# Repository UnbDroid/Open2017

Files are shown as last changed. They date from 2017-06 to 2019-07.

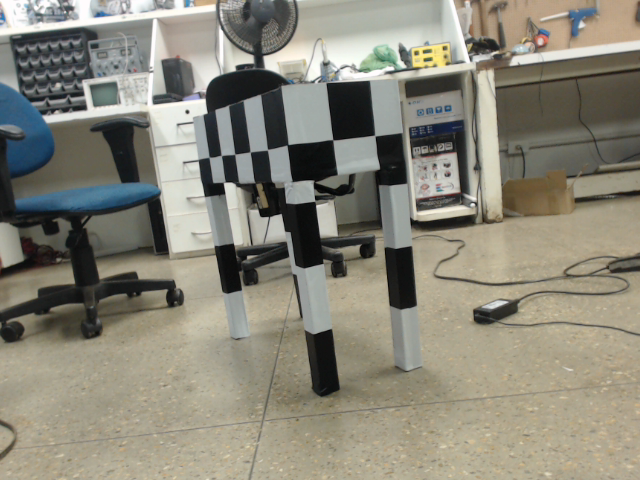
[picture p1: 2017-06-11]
Codigos/Vision/src/053.png

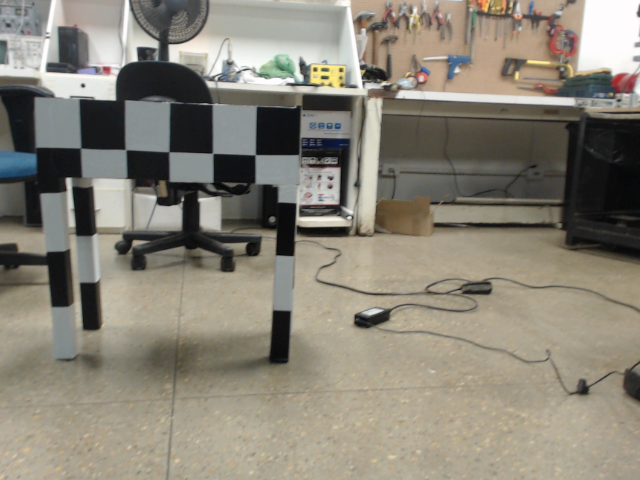
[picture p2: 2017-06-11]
Codigos/Vision/src/025.png

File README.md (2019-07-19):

# Open2017
Development repository for DROID's project files for Latin American Robotics Competition (LARC) 2017 category IEEE-Open  
The robot is supposed to milk a a cow (simulation of a real world problem)
# Photo of the robot:


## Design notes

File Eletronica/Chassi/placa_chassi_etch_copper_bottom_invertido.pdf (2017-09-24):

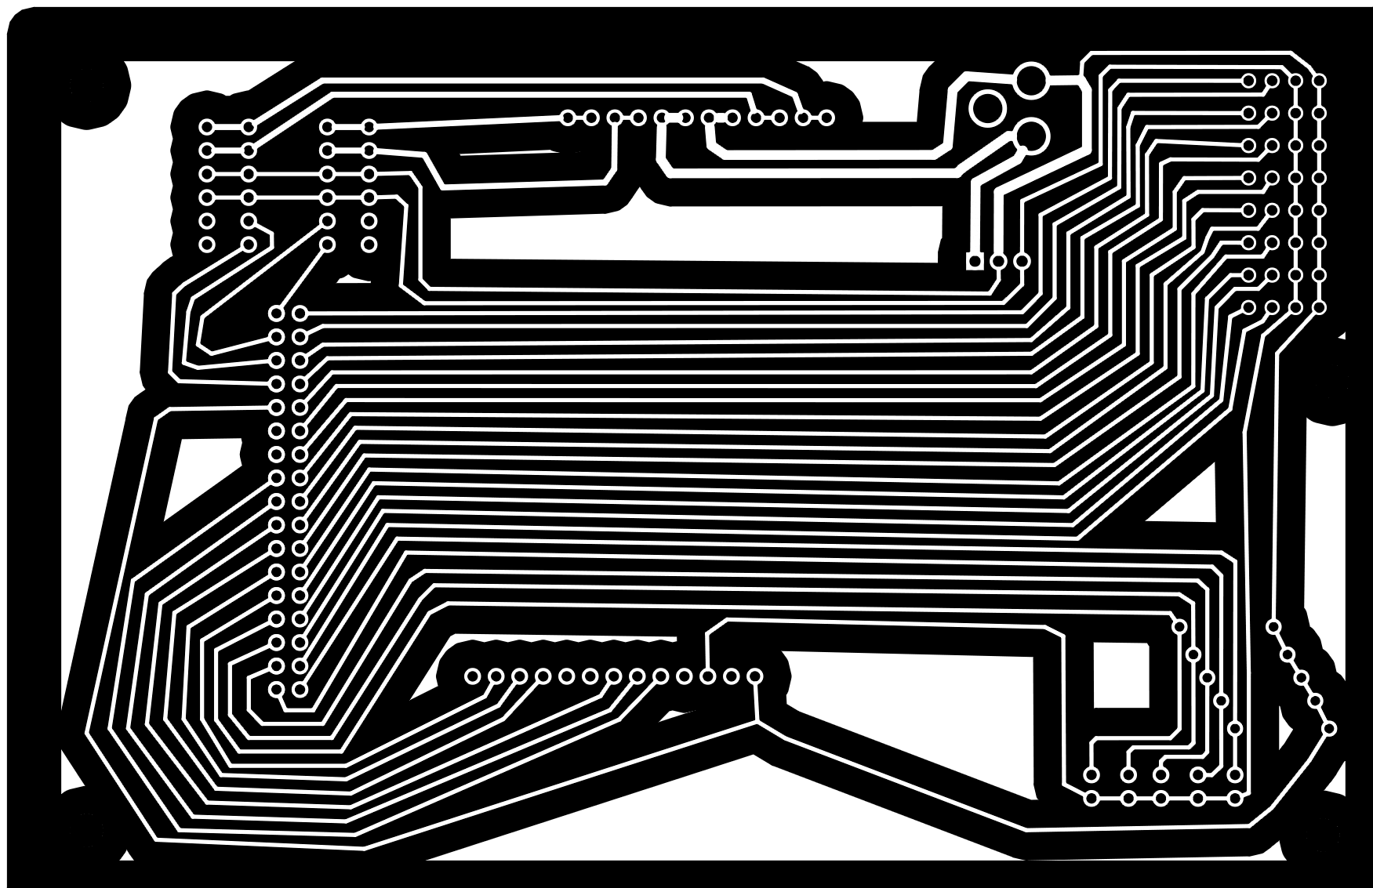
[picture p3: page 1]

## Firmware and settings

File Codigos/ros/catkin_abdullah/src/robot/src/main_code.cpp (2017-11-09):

	#include <cmath>
	#include <vector>
	#include <iostream>
	#include <fstream>
	using namespace std;

	#define PI 3.14159265f


/*---------------------------------------definicoes ROS-------------------------------------------*/
	#include "ros/ros.h"
	#include "ros/time.h"
	#include "arduino_msgs/StampedInt32.h"
	#include "arduino_msgs/StampedInt64.h"
	#include "arduino_msgs/StampedFloat32.h"
	#include "arduino_msgs/StampedFloat64.h"	

	ros::Publisher pubM_int64;
	ros::Publisher pubM_float64;
	ros::Publisher pubN_int32;
	ros::Publisher pubN_float32;

	ros::Publisher pubDEBUG;

	ros::Publisher pub_VCestrategia;
	ros::Subscriber sub_VCestrategia;

	ros::Subscriber subM_int64;
	ros::Subscriber subM_float64;
	ros::Subscriber subN_int32;
	ros::Subscriber subN_float32;

	ros::Publisher pubVis_int32;
	ros::Subscriber subVis_float64;
/*------------------------------------------------------------------------------------------------*/

/*-----------------------------------declaracoes das funcoes--------------------------------------*/
	bool ehSonar(int id);
	bool ehToque(int id);
	void messageMInt64Cb( const arduino_msgs::StampedInt64& aM_int64_msg);
	void messageMFloat64Cb( const arduino_msgs::StampedFloat64& aM_float64_msg);
	void messageNInt32Cb( const arduino_msgs::StampedInt32& aN_int32_msg);
	void messageNFloat32Cb( const arduino_msgs::StampedFloat32& aN_float32_msg);
	void messageVisFloat64Cb( const arduino_msgs::StampedFloat64& vis_float64_msg);
	void VCestrategiaCB(const arduino_msgs::StampedInt32& VCestrategia_msg);
	void initROS();
	void SendFloatMega(int id, double data);
	void SendIntMega(int id, long long int data);	
	void SendFloatUno(int id, float data);
	void SendIntUno(int id, long int data);
	void SendVel(float DIR, float ESQ);
	void GiraEmGraus(float angulo);
	float DeGrausParaRadianos(float angulo);
	float DeRadianosParaDegraus(float angulo);
	vector<float> AnaliseLugarDaVaca(float x1, float y1, float x2, float y2, float theta);
	void TrajetoriaSuaveAteAVaca(float x1, float y1, float x2, float y2, float theta);
	void andaRetoDistVelTempo(float dist, float vel);
	void algoritmo();
	void atualizaLocalizacao(int id, float value);
	void inicializarVariaveis();
	vector<int> posicaoPraMatriz(int x, int y);
	vector<float> matrizPraPosicao(int i, int j);
	void preencheMatriz();
	double rotacoesPorSegundoParaLinear(float dado);
	bool ehGarra(int id);
	void SendIntVCestrategia(int id, long int data);
	void andaRetoDistVelIntegrando(float distancia, float vel);
	void buscaMelhorCaminho(int NoAtual, int iO, int jO);
	class NoDoMapa;
	class Vertice;
	int deIJparaCasaNoVetor(int i, int j);
	vector<int> deCasaNoVetorParaIJ(int casaNoVetor);
	void printaGrafo();
	bool criaGrafoComPesos();
	void buscaMelhorCaminho(int NoAtual, int iO, int jO);
	bool EhNoEixoX(int no1, int no2);
	int AnguloQuePrecisaPraGirar(int noObjetivo);
	bool ehPraPassarNaPorta();
	void rotinaPassarNaPorta();
	void andaDevagarChecandoPortaAteAcabarOVao(bool praFrente,int sensorParaChecar, bool comecandoNaParede);
	int checaAnguloComTolerancia();
	int absolutoINT(int valor);
	float absolutoFLOAT(float valor);
	void AndaDeNoAtualParaObjetivo();
/*------------------------------------------------------------------------------------------------*/

/*-----------------------------------definicoes mapeamento----------------------------------------*/
	#define CASA_INICIAL_I 4
	#define CASA_INICIAL_J 0


	
	#define CASA_I_BALDE  
	#define CASA_J_BALDE 

	#define CASA_I_VACA1 
	#define CASA_J_VACA1 

	#define CASA_I_VACA2 
	#define CASA_J_VACA2

	#define CASA_I_VACA3 
	#define CASA_J_VACA3

	int noAtual = 24;
 

	//////////////define na hora que a posicao eh escolhida 
	
	#define CASA_I_MESA_PEGAR 4
	#define CASA_J_MESA_PEGAR 5

	#define CASA_I_MESA_DEVOLVER 5
	#define CASA_J_MESA_DEVOLVER 1
	
	#define LADO_Y_I_DA_ARENA 400
	#define LADO_X_J_DA_ARENA 300

	vector<float> ladosQuadrado(2);	
	
	#define I 0
	#define J 1

	#define COLUNAS_MAPA 6
	#define LINHAS_MAPA 8

	//vector<vector<int> > mapa(LINHAS_MAPA, vector<int>(COLUNAS_MAPA));
	class Vertice{
		public:	
			double peso;
	        NoDoMapa* noAdjacente;
	};

	class NoDoMapa{
		public:
			vector<float> centro;
	        int NumeroDoNo;
	        int informacaoDoQuadrado;
	        bool Visitado;
			vector<Vertice> adjacentes;
			void adicionaAdjacente(int casaNo, int peso);
		NoDoMapa(){
			centro = vector<float>(2);
		}
	};


	vector<vector<NoDoMapa> > GrafoMapa(LINHAS_MAPA, vector<NoDoMapa>(COLUNAS_MAPA));
/*------------------------------------------------------------------------------------------------*/

/*-------------------------------------definicoes locomocao---------------------------------------*/

	#define VELOCIDADE_MAXIMA 1.3f
	#define VELOCIDADE_ALTA	1.0f
	#define VELOCIDADE_NORMAL 0.75f
	#define VELOCIDADE_BAIXA 0.5f
	#define VELOCIDADE_BAIXISSIMA 0.2f
	
	#define USDIREITA 1
	#define USESQUERDA 0

	#define GIRA 300
	#define VEL_REF_DIR 301
	#define VEL_REF_ESQ 302
	#define TRAVAR 303
	#define VELOCIDADE_CRU 304

	#define PARAMETRO_DERRAPAGEM_ROTACOES_METROS 8.625f ///era pra ser 8	
	#define DIAMETRO_MEDIO 9.5125f


	#define EIXO_XPOSITIVO 0
	#define EIXO_XNEGATIVO 1 
	#define EIXO_YPOSITIVO 2
	#define EIXO_YNEGATIVO 3

	#define TOLERANCIA_ANGULO 15
	#define PERDIDO_BRODER -1

	#define AJUSTE_POS_ACHAR_PORTA 5.0

	vector<float> posicao(3);

	double velocidadeIntegrada;
	vector<int> SequenciaDeNosParaSeguir;

	#define X 0
	#define Y 1
	#define ANGULO 2
	
	#define ANGULO_MINIMO_CORRECAO_GIRO 45
	#define CORRECAO_GIRO 6

	#define ACABOU_GIRO 1
	#define ACABOU_ATUAL 2
	#define DISTANCIA_MIN_AJUSTE_VACA 30.0f
	
	#define PASSO_LOCOMOCAO 50
	#define PASSINHO 4

	#define ANDAR 1
	#define GIRAR 2
/*------------------------------------------------------------------------------------------------*/

/*---------------------------------definicoes dos sensores US-------------------------------------*/



	#define FRENTE_R 0
	#define FRENTE_L 3

	#define TRAS_R 2
	#define TRAS_L 5

	#define LADO_R 4
	#define LADO_L 7

	#define CIMA_R 1
	#define CIMA_L 6

	#define VALOR_VAO 25

	#define US_MAX_DIST 200

	#define NUM_IDEN_US 100

	#define QUANTIDADE_SENSOR_US 8
	
	#define TAMANHO_MEDIANA 5
	#define VALOR_MEDIANA 2
	//sinal chega do arduino com o id(USn) = (n-1) + NUM_IDEN_US... exemplo: id do US5 = (5-1) + 100 = 104

	#define alfa_US 0.8f

	class Us{
  		public:
	  		float valor;
	  		vector<float> valores;
	  		long long int vezes_lido;
		Us(){
			valores = vector<float>(TAMANHO_MEDIANA);
		}
	};

	vector<Us> ultrassom(QUANTIDADE_SENSOR_US);
/*------------------------------------------------------------------------------------------------*/

/*-----------------------------definicoes dos sensores de TOQUE-----------------------------------*/
	#define TOQUE1 0
	#define TOQUE2 1
	#define TOQUE3 2
	#define TOQUE4 3
	#define TOQUE5 4
	#define TOQUE6 5
	#define TOQUE7 6

	#define TOQUE8 7
	#define TOQUE9 8

	#define NUM_IDEN_TOQUE 200
	#define QUANTIDADE_SENSOR_TOQUE 9

	vector<bool> toque(QUANTIDADE_SENSOR_TOQUE);//(QUANTIDADE_SENSOR_TOQUE, false);
/*------------------------------------------------------------------------------------------------*/

/*-------------------------------------------Garra------------------------------------------------*/
	#define QUANTIDADE_MOTORES_GARRA 1

	#define MOTOR_PASSO_X 0 //MOVE MOTOR NO EIXO X PARA SE ALINHAR
	#define ANDA_ROBO 1  //MANDA ROBO IR PARA FRENTE PARA PEGAR COPO
	#define ACABOU_GARRA 2 //INFORMA QUE ACABOU MOVIMENTAÇÃO

	#define ANGULO_TANQUE 3 //ANGULO DO ROBO AO TANQUE
	#define DISTANCIA_TANQUE 4 //DISTANCIA DO ROBO AO TANQUE

	#define DISTANCIA_AVANCO_ROBO 20

	#define TANQUE 10
	#define GARRA 20

	#define NUM_IDEN_VISAO 600

/*
	#define QUANTIDADE_MOTORES_GARRA 5
	
	#define MOTOR_PASSO_X 0 
	#define MOTOR_PASSO_Y 1
	#define MOTOR_SERVO_COTOVELO 2
	#define MOTOR_SERVO_PULSO 3 
	#define MOTOR_SERVO_ATUADOR 4

	#define ACABOU_GARRA 666
	
	#define ANDA_PRA_FRENTE_GARRA 667 
	
	#define NUM_IDEN_GARRA 600

	#define VELOCIDADE_COPO 0.24f

	#define PEGA_COPO 10
	#define DESCARREGA_COPO 20 
	#define DEVOLVE_COPO 30
*/
/*------------------------------------------------------------------------------------------------*/

/*--------------------------------------definicoes da VISAO---------------------------------------*/
	#define NUM_IDEN_VISION 500
	#define VIS_X1 1
	#define VIS_Z1 2
	#define VIS_X2 3
	#define VIS_Z2 4
	#define VIS_ERR 5
	#define VIS_NOTFOUND 6
	double cow_pos_x1, cow_pos_x2, cow_pos_z1, cow_pos_z2, cow_pos_err;
	bool foundCow = 0;
/*------------------------------------------------------------------------------------------------*/

class Ocupacao{
	public:
		bool giro;
		bool garraGeral;
};

Ocupacao ocupado;


template<typename ItemType>
unsigned Partition(ItemType* array, unsigned f, unsigned l, ItemType pivot)
{
    unsigned i = f-1, j = l+1;
    while(true)
    {
        while(pivot < array[--j]);
        while(array[++i] < pivot);
        if(i<j)
        {
            ItemType tmp = array[i];
            array[i] = array[j];
            array[j] = tmp;
        }
        else
            return j;
    }
}

template<typename ItemType>
void QuickSortImpl(ItemType* array, unsigned f, unsigned l)
{
    while(f < l)
    {
        unsigned m = Partition(array, f, l, array[f]);
        QuickSortImpl(array, f, m);
        f = m+1;
    }
}

template<typename ItemType>
void QuickSort(ItemType* array, unsigned size)
{
    QuickSortImpl(array, 0, size-1);
}

bool ehSonar(int id)
{
	id = id - NUM_IDEN_US;
	if (id < QUANTIDADE_SENSOR_US && id >= 0)	 return true;
	else	return false;
}

bool ehToque(int id)
{
	id = id - NUM_IDEN_TOQUE;
	if (id < QUANTIDADE_SENSOR_TOQUE && id >= 0)	 return true;
	else	return false;
}



void Delay(double time)
{
    double t1=0, t0=0;
    t0 = ros::Time::now().toSec();
    while((t1-t0)<time && ros::ok()){
        t1 = ros::Time::now().toSec();
        ros::spinOnce();
    }
}
/*----------------------------------------callbacks------------------------------------------------*/
	void messageMInt64Cb( const arduino_msgs::StampedInt64& aM_int64_msg)
	{
		if(ehSonar(aM_int64_msg.id))
		{
			int usPos = aM_int64_msg.id - NUM_IDEN_US; 
			int valor ;
			valor = (aM_int64_msg.data <= 0.1) ? US_MAX_DIST : aM_int64_msg.data;	
			//sonar[aN_int32_msg.id - NUM_IDEN_US] = valor * alfa_US + sonar[aN_int32_msg.id - NUM_IDEN_US] * (1 - alfa_US);
			float valorf = (float)valor ; 
			long long int iterator = ultrassom[usPos].vezes_lido ;
		    ultrassom[usPos].valores[iterator % TAMANHO_MEDIANA] = valorf;
		    float valores[TAMANHO_MEDIANA];
		    for(unsigned i = 0; i < TAMANHO_MEDIANA; ++i)
		      	valores[i] = ultrassom[usPos].valores[i];
		    QuickSort(valores,TAMANHO_MEDIANA);
		    //ultrassom[usPos].value = values[MEDIAN_VALUE];
		    valorf = valores[VALOR_MEDIANA];
		    ultrassom[usPos].valor = valorf * alfa_US + ultrassom[usPos].valor * ( 1- alfa_US);
		    ultrassom[usPos].vezes_lido++;
		}else if (ehToque(aM_int64_msg.id)) 
			toque[aM_int64_msg.id - NUM_IDEN_TOQUE] = aM_int64_msg.data;


	}


	void messageMFloat64Cb( const arduino_msgs::StampedFloat64& aM_float64_msg)
	{
		
	}

	void messageNInt32Cb( const arduino_msgs::StampedInt32& aN_int32_msg)
	{
		if (aN_int32_msg.id == ACABOU_GIRO)		ocupado.giro = false;
	}

	void messageNFloat32Cb( const arduino_msgs::StampedFloat32& aN_float32_msg)
	{
		if (aN_float32_msg.id == VELOCIDADE_CRU)		velocidadeIntegrada += 100*(rotacoesPorSegundoParaLinear(aN_float32_msg.data)* 0.02);
		//o 100 é para mudar de metros apra centimetros (medida que a gente usa no codigo)
	}

	void VCestrategiaCB(const arduino_msgs::StampedInt32& VCestrategia_msg)
	{

	}

	void messageVisFloat64Cb( const arduino_msgs::StampedFloat64& vis_float64_msg)
	{
		if(vis_float64_msg.id == NUM_IDEN_VISION + VIS_X1)
		{
			//cout << "Got x1: ";
			cow_pos_x1 = vis_float64_msg.data;
			//cout << vis_float64_msg.data;
			//cout << "\n";
		} else if(vis_float64_msg.id == NUM_IDEN_VISION + VIS_Z1) {
			//cout << "Got z1: ";
			cow_pos_z1 = vis_float64_msg.data;
			//cout << vis_float64_msg.data;
			//cout << "\n";
		} else if(vis_float64_msg.id == NUM_IDEN_VISION + VIS_X2) {
			//cout << "Got x2: ";
			cow_pos_x2 = vis_float64_msg.data;
			//cout << vis_float64_msg.data;
			//cout << "\n";
		} else if(vis_float64_msg.id == NUM_IDEN_VISION + VIS_Z2) {
			//cout << "Got z2: ";
			cow_pos_z2 = vis_float64_msg.data;
			//cout << vis_float64_msg.data;
			//cout << "\n";
		} else if(vis_float64_msg.id == NUM_IDEN_VISION + VIS_ERR) {
			//cout << "Got error value: ";
			cow_pos_err = vis_float64_msg.data;
			foundCow = 1;
			//cout << vis_float64_msg.data;
			//cout << "\n";
		} else if(vis_float64_msg.id == NUM_IDEN_VISION + VIS_NOTFOUND) {
			foundCow = 0;
		}
	}
/*-------------------------------------------------------------------------------------------------*/
/*-------------------------------------comunicacao ROS---------------------------------------------*/
	
	void initROS(ros::NodeHandle nh)
	{
		pubM_int64 = nh.advertise<arduino_msgs::StampedInt64>("raspberryM_int64", 1000);
		pubM_float64 = nh.advertise<arduino_msgs::StampedFloat64>("raspberryM_float64", 1000);
		subM_int64 = nh.subscribe("arduinoM_int64", 1000, messageMInt64Cb);
		subM_float64 = nh.subscribe("arduinoM_float64", 1000, messageMFloat64Cb);
		
		pubN_int32 = nh.advertise<arduino_msgs::StampedInt32>("raspberryN_int32", 1000);
		pubN_float32 = nh.advertise<arduino_msgs::StampedFloat32>("raspberryN_float32", 1000);
		subN_int32 = nh.subscribe("arduinoN_int32", 1000, messageNInt32Cb);
		subN_float32 = nh.subscribe("arduinoN_float32", 1000, messageNFloat32Cb);
		pubDEBUG = nh.advertise<arduino_msgs::StampedFloat32>("debug", 1000);

		pub_VCestrategia = nh.advertise<arduino_msgs::StampedInt32>("estrategiaVCT", 1000); 
		sub_VCestrategia = nh.subscribe("VCestrategia", 1000, VCestrategiaCB);

		pubVis_int32 = nh.advertise<arduino_msgs::StampedInt32>("Vision_int32", 1000); 
		subVis_float64 = nh.subscribe("Vision_float64", 1000, messageVisFloat64Cb);

	}

	void SendFloatMega(int id, double data)
	{   
		arduino_msgs::StampedFloat64 float64_msg;
		float64_msg.id = id;
		float64_msg.data = data;
		pubM_float64.publish(float64_msg);
	}
	void SendDebug(int id, float data)
	{
		arduino_msgs::StampedFloat32 float32_msg;
		float32_msg.id = id;
		float32_msg.data = data;
		pubDEBUG.publish(float32_msg);
	}

	void SendIntMega(int id, long long int data)
	{    
		arduino_msgs::StampedInt64 int64_msg;
		int64_msg.id = id;
		int64_msg.data = data;
		pubM_int64.publish(int64_msg);
	}

	void SendIntVCestrategia(int id, long int data)
	{    
		arduino_msgs::StampedInt32 int32_msg;
		int32_msg.id = id;
		int32_msg.data = data;
		pub_VCestrategia.publish(int32_msg);
	}


	void SendFloatUno(int id, float data)
	{    
		arduino_msgs::StampedFloat32 float32_msg;
		float32_msg.id = id;
		float32_msg.data = data;
		pubN_float32.publish(float32_msg);
	}

	void SendIntUno(int id, long int data)
	{    
		arduino_msgs::StampedInt32 int32_msg;
		int32_msg.id = id;
		int32_msg.data = data;
		pubN_int32.publish(int32_msg);
	}

	void SendIntVision(int id, long int data)
	{
		arduino_msgs::StampedInt32 int32_msg;
		int32_msg.id = id;
		int32_msg.data = data;
		pubVis_int32.publish(int32_msg);
	}

	void SendVel(float DIR, float ESQ)
	{
		SendFloatUno(VEL_REF_DIR, DIR);
		SendFloatUno(VEL_REF_ESQ, ESQ);
	}
/*-------------------------------------------------------------------------------------------------*/
/*-------------------------------------conversoes--------------------------------------------------*/
	float DeGrausParaRadianos(float angulo)
	{
		return (angulo*PI)/180;
	}

	float DeRadianosParaDegraus(float angulo)
	{
		return (angulo*180)/PI;
	}

	double rotacoesPorSegundoParaLinear(float dado)
	{
		return (dado*(DIAMETRO_MEDIO)/(PARAMETRO_DERRAPAGEM_ROTACOES_METROS*PI));
	}
/*-------------------------------------------------------------------------------------------------*/
/*----------------------------------------andar&Girar----------------------------------------------*/
	void atualizaLocalizacao(int id, float value)
	{
		if (id == ANDAR){
			posicao[X] += value * cos(DeGrausParaRadianos(posicao[ANGULO]));
			posicao[Y] += value * -sin(DeGrausParaRadianos(posicao[ANGULO])); 
		}else if (id == GIRAR){
			posicao[ANGULO] = ((posicao[ANGULO]+value)< 0)? (posicao[ANGULO]+ 360 + value) : posicao[ANGULO]+value;
			posicao[ANGULO] = (posicao[ANGULO]>360) ? posicao[ANGULO] - 360 : posicao[ANGULO] ;
		}
	}

	void GiraEmGraus(float angulo)
	{
		
		SendDebug(0, angulo);
		if (angulo >= 359.8)
		{
			angulo = angulo - 360;
		}else if(angulo <= -359.8)
		{
			angulo = angulo + 360;
		}

		SendDebug(1, angulo);
		if (angulo>0.2 || angulo<-0.2)
		{
			ocupado.giro = true;
		}
		SendFloatUno(GIRA,angulo);
		while(ocupado.giro && ros::ok()){	
			SendDebug(8, 0);	
			ros::spinOnce();
		}
		atualizaLocalizacao(GIRAR, angulo);
	}

	void andaRetoDistVelTempo(float dist, float vel)
	{
		double tempo=0;
		tempo = dist*2.682871209/100*absolutoFLOAT(vel); /// de rotacoes por segundo para metros por segundo
		dist = (vel > 0) ? dist : -dist;
		SendVel(vel, vel);
		SendVel(vel, vel);
		Delay(tempo);
		SendVel(0.0,0.0);
		SendFloatUno(TRAVAR,0);
		atualizaLocalizacao(ANDAR, dist);
	}

	void andaRetoDistVelIntegrando(float distancia, float vel)
	{
		velocidadeIntegrada = 0.0;
		SendVel(vel,vel);
		//SendVel(vel,vel);
		//SendVel(vel,vel);
		//cout<<"andei dist = "<< distancia << endl;
		while(velocidadeIntegrada < distancia && ros::ok())
		{
			ros::spinOnce();		
		}
		distancia = (vel > 0) ? distancia : -distancia;
		SendVel(0,0);
		SendFloatUno(TRAVAR,0);
		atualizaLocalizacao(ANDAR, distancia);
	}
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
int main(int argc, char **argv)
{
	ros::init(argc, argv, "main_node");
	ros::NodeHandle nh;
	initROS(nh);
	inicializarVariaveis();
	Delay(3);
	ros::Rate loop_rate(10);
	while (ros::ok())
	{
		algoritmo();
		ros::spinOnce();
		loop_rate.sleep();
	}
	return 0;
}

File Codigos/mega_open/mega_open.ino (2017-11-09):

#include "roscom.h"
#include "US.h"
#include "tasks.h"
#include "toque.h"
#include "GarraOpen.h"


//"ESTADOS" que a estrategia pode mandar para o mega
#define GARRA_DENTRO 1  //MOVE A GARRA PARA ORDENHA
#define GARRA_FORA 2 //TIRA GARRA DA ORDENHA
#define SENSORES 3 
#define DESPEJA 4 //MOVE GARRA PARA DESPEJAR 
#define PREPARA_COPO 5 //MOVE GARRA PARA POSICAO MAIS BAIXA COM ATUADOR ABERTO PARA ENTRADA OU SAIDA DE COPO
#define MAMADOR 6 //DEVE FECHAR O MAMADOR E MOVER O MOTOR DC

int STATE;
GarraOpen Garra;

void messageInt64Cb( const arduino_msgs::StampedInt64& r_int64_msg)
{   
  if(Garra.ehGarra(r_int64_msg.id))
  {
      int flag_resultado = Garra.trataGarra(r_int64_msg.id, r_int64_msg.data);
      sendInt64(r_int64_msg.id,flag_resultado);
  }
}

void messageFloat64Cb( const arduino_msgs::StampedFloat64& r_float64_msg)
{
}

void despeja()
{
    Garra.moveY(0);
    Garra.moveCotovelo (COTOVELO_FRENTE);
    Garra.movePulso (PULSO_BAIXO);
    Garra.moveY(10);
    Garra.moveY(0);
    Garra.movePulso (PULSO_CIMA);
}


void preparaCopo(){
  Garra.moveY(130);
  Garra.moveAtuador(ATUADOR_ABRE);
  Garra.moveCotovelo(COTOVELO_FRENTE);
  Garra.movePulso(PULSO_CIMA);
}

void taskUSCallback1()
{
  readUS(FRENTE_R);
  readUS(TRAS_L);
  sendInt64( FRENTE_R + NUM_IDEN_US , USReadings[FRENTE_R]);
  sendInt64(TRAS_L + NUM_IDEN_US , USReadings[TRAS_L]);
}

void taskUSCallback2()
{
  readUS(FRENTE_L);
  readUS(TRAS_R);
  sendInt64(FRENTE_L + NUM_IDEN_US , USReadings[FRENTE_L]);
  sendInt64(TRAS_R + NUM_IDEN_US , USReadings[TRAS_R]);

}

void taskUSCallback3()
{
  readUS(CIMA_R);
  readUS(LADO_L);
  sendInt64(CIMA_R + NUM_IDEN_US , USReadings[CIMA_R]);
  sendInt64(LADO_L + NUM_IDEN_US , USReadings[LADO_L]);
}

void taskUSCallback4()
{
  readUS(CIMA_L);
  readUS(LADO_R);
  sendInt64(CIMA_L + NUM_IDEN_US , USReadings[CIMA_L]);
  sendInt64(LADO_R + NUM_IDEN_US , USReadings[LADO_R]);
}

void taskTOQUECallback()
{
   lerSensoresToque();
   int i = 0;
   while(i<QUANTIDADE_SENSOR_TOQUE)
   {
        if(toque[i]!=oldToque[i]){
             sendInt64(i + NUM_IDEN_TOQUE, toque[i]);
             oldToque[i] = toque[i];
        }
        i++;
   }
}

//8 sensores US
//9 sensores de toque

void setup()
{
  initializeROS();
  startSENSORTOQUE();
  //Garra.setupGarra(); //OBSERVAÇÃO!!!!!!!!!!!!!!!! PODE HAVER LOOP INFINITO AQUI SE A GARRA NAO TOCAR NOS SENSORES DE FIM DE CURSO
  start_TASKS();
  STATE = SENSORES;
}

void loop()
{
  switch(STATE)
  {
      case GARRA_DENTRO: //Move a garra para posição de ordenha
          //Garra.segueTrajetoria(0);
          break;
      case GARRA_FORA: //Move a garra para fora da posição de ordenha, para despejar ou devolver
          //Garra.segueTrajetoria(1);
          break;
      case DESPEJA: //Move a garra para despejar
          //Garra.despeja();
          break;
      case PREPARA_COPO: //Move a garra para pegar ou devolver o copo, obs: Atuador fica aberto
          //Garra.pega();
          break;
      case MAMADOR: //Função para ordenhar a vaca
          break;
      case SENSORES:
          runner.execute();
          break;
      default:
          runner.execute();
          break;
  }
  nh.spinOnce();
}

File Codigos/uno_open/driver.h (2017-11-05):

#ifndef DRIVER_H
#define DRIVER_H
// Defines ----------------------------------------------------------------------------------------------------------

#define IN1_E 25
#define IN2_E 23


#define IN1_D 27
#define IN2_D 29

#define PWM_E 4

#define PWM_D 5

#define POT_MAX_ESQUERDA 255
#define POT_MAX_DIREITA 255
#define POT_MIN_ESQUERDA 10
#define POT_MIN_DIREITA 10

// Variaveis --------------------------------------------------------------------------------------------------------

float pot_direita = 0;
float pot_esquerda = 0;

float velocidade_ReferenciaEsquerda = 0;
float velocidade_ReferenciaDireita = 0;

bool forward_esquerda = true;
bool forward_direita = true;
bool dir;

// Funcoes -----------------------------------------------------------------------------------------------------------

void startDriver () {
  pinMode(IN1_E, OUTPUT);
  pinMode(IN2_E, OUTPUT);
  pinMode(IN1_D, OUTPUT);
  pinMode(IN2_D, OUTPUT);
  pinMode(PWM_E, OUTPUT);
  pinMode(PWM_D, OUTPUT);
}

void direitaEixo (int potEsquerda, int potDireita) {
  analogWrite(PWM_E, potEsquerda);
  analogWrite(PWM_D, potDireita);
  digitalWrite(IN1_E, HIGH);
  digitalWrite(IN2_E, LOW);
  digitalWrite(IN1_D, HIGH);
  digitalWrite(IN2_D, LOW);

}

void esquerdaEixo (int potEsquerda, int potDireita) {
  analogWrite(PWM_E, potEsquerda);
  analogWrite(PWM_D, potDireita);
  digitalWrite(IN1_E, LOW);
  digitalWrite(IN2_E, HIGH);
  digitalWrite(IN1_D, LOW);
  digitalWrite(IN2_D, HIGH);

}

void frente(int potEsquerda, int potDireita) {
  analogWrite(PWM_E, potEsquerda);
  analogWrite(PWM_D, potDireita);
  if(dir==1){
    digitalWrite(IN1_E, HIGH);
    digitalWrite(IN2_E, LOW);
    digitalWrite(IN1_D, LOW);
    digitalWrite(IN2_D, HIGH);
  }else{
    digitalWrite(IN1_E, LOW);
    digitalWrite(IN2_E, HIGH);
    digitalWrite(IN1_D, HIGH);
    digitalWrite(IN2_D, LOW);    
  }
}

void tras(int potEsquerda, int potDireita) {
  analogWrite(PWM_E, potEsquerda);
  analogWrite(PWM_D, potDireita);
  
  if(dir==1){
    digitalWrite(IN1_E, LOW);
    digitalWrite(IN2_E, HIGH);
    digitalWrite(IN1_D, HIGH);
    digitalWrite(IN2_D, LOW);
  }else{
    digitalWrite(IN1_E, HIGH);
    digitalWrite(IN2_E, LOW);
    digitalWrite(IN1_D, LOW);
    digitalWrite(IN2_D, HIGH);   
  }
}

void parar () {
  digitalWrite(IN1_E, LOW);
  digitalWrite(IN2_E, LOW);
  digitalWrite(IN1_D, LOW);
  digitalWrite(IN2_D, LOW);
}

void travar () {
  digitalWrite(IN1_E, HIGH);
  digitalWrite(IN2_E, HIGH);
  digitalWrite(IN1_D, HIGH);
  digitalWrite(IN2_D, HIGH);
}

void setVelocidade() {
  
  if ((pot_esquerda > POT_MAX_ESQUERDA) && (velocidade_ReferenciaEsquerda > 0)) {
    pot_esquerda = POT_MAX_ESQUERDA;
    forward_esquerda = true;
  } 
  else if ((pot_esquerda < POT_MIN_ESQUERDA) && (velocidade_ReferenciaEsquerda > 0)) {
    pot_esquerda = POT_MIN_ESQUERDA;
    forward_esquerda = true;
  }
  else if ((-pot_esquerda > POT_MAX_ESQUERDA) && (velocidade_ReferenciaEsquerda < 0)) {
    pot_esquerda = POT_MAX_ESQUERDA;
    forward_esquerda = false;
  } 
  else if ((pot_esquerda < POT_MIN_ESQUERDA) && (velocidade_ReferenciaEsquerda < 0)) {
    if (abs(pot_esquerda) < POT_MIN_ESQUERDA){
      pot_esquerda = POT_MIN_ESQUERDA;
    }    
    forward_esquerda = false;
  }
  else if ((pot_esquerda > 0) && (velocidade_ReferenciaEsquerda < 0)) {
    pot_esquerda = POT_MIN_ESQUERDA;
    forward_esquerda = false;
  }

  if (pot_esquerda < 0 && velocidade_ReferenciaEsquerda < 0) {
    forward_esquerda = false;
    pot_esquerda = abs(pot_esquerda);
  }
  else if(pot_esquerda > 0 && velocidade_ReferenciaEsquerda > 0) {
    forward_esquerda = true;
  }

  
  if ((pot_direita > POT_MAX_DIREITA) && (velocidade_ReferenciaDireita > 0)) {
    pot_direita= POT_MAX_DIREITA;
    forward_direita = true;
  } 
  else if ((pot_direita < POT_MIN_DIREITA) && (velocidade_ReferenciaDireita > 0)) {
    pot_direita = POT_MIN_DIREITA;
    forward_direita = true;
  }
  else if ((-pot_direita > POT_MAX_DIREITA) && (velocidade_ReferenciaDireita < 0)) {
    pot_direita= POT_MAX_DIREITA;
    forward_direita = false;
  } 
  else if ((pot_direita < POT_MIN_DIREITA) && (velocidade_ReferenciaDireita < 0)) {
    if (abs(pot_direita) < POT_MIN_DIREITA){
      pot_direita = POT_MIN_DIREITA;
    }    
    forward_direita = false;
  }
  else if ((pot_direita > 0) && (velocidade_ReferenciaDireita < 0)) {
    pot_direita = POT_MIN_DIREITA;
    forward_direita = false;
  }
  
  if (pot_direita < 0 && velocidade_ReferenciaDireita < 0){
    forward_direita = false;
    pot_direita = abs(pot_direita);
  }
  else if (pot_direita > 0 && velocidade_ReferenciaDireita > 0){
    forward_direita = true;
  }
  
  if (forward_direita && forward_esquerda) {
    frente(pot_esquerda, pot_direita);
  }
  else if (!forward_direita && !forward_esquerda){
    tras(pot_esquerda, pot_direita);
  }
  else if(forward_direita && !forward_esquerda){
    esquerdaEixo(pot_esquerda, pot_direita);
  }
  else if  (!forward_direita && forward_esquerda){
    direitaEixo(pot_esquerda, pot_direita);  
  }
}
#endif

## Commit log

2017-06-11 codigo para gerar imagens Ground Truth, recebendo da pasta src e alocando os resultados na pasta GT
2017-06-11 Fixed exit with esc button bug
2017-06-30 Upload do código de retangulos + build
    Para compilar código usar >>sh build_all.sh
2017-07-01 Modified findChess.py to filter the true points of interest
2017-07-01 Pequenas aperfeiçoamentos
    Pequenas alterações na área considerada da vaca, e amostragem dos quadrados dentro dessa área por meio de X azuis
2017-07-04 codigo final
    Com opção de salvar imagens
2017-08-05 Significantly improved filtering algorithm
2017-08-30 teste de comunicacao reversa do rasp
2017-09-04 adicionando arduino nano
2017-09-11 adicionando biblioteca de locomoção, no arduino uno, ler encoders controle da ponte H e outras coisas
2017-09-12 correçao algoritmo arduino uno
2017-09-17 codigo teste da biblioteca dos motores, adicionando mini-biblioteca US
2017-09-18 subindo o codigo do controlador da leticia já alterado junto com ela e testado para funcionar no robo da open
2017-09-18 alterações nos parametros dos motores no codigo da letiia para andar mais reto
2017-09-20 adicionando a biblioteca do giro, adaptando o codigo do uno para o controlador e o giro ao mesmo tempo
2017-09-20 Update gyro.h
    Correção da variavel STATE. Dps do giro
2017-09-23 acressentando o código de teste dos drives cedidos pela TDTEC para os motores de passo
2017-09-23 adicionando o projeto da placa do chassi no repositorio
    [placa_chassi.fzz]
2017-09-23 arrumando o re no controlador e adaptando a bibioteca driver
2017-09-23 corrigindo besteira em relaçao a direcao do giro
    [uno_open.ino]
2017-09-24 tamanho do encaixe do drive regulado
    [placa_chassi.fzz]
2017-09-24 codigo sintetizado de seguir a vaca pegando infos da visao
2017-09-24 projeto da placa do chassi pronto, eu acho
    [placa_chassi.fzz]
2017-09-24 correções no circuito
    [placa_chassi.fzz]
2017-09-25 tratamento de dados e filtragem US e toque
2017-09-27 sensoriamento e processamento paralelo no mega e adaptando a parte do ROS pra isso
2017-09-27 corrigindo besteira (iterador nao sendo incrementado)
    [mega_open.ino]
2017-09-29 adicionando a nova biblioteca de giro e arrumando besteiras
2017-10-05 ultimos codigos testados no robo para andar, MUDAMOS PRA MEGA
2017-10-09 melhorias em relacao a memoria, arduino e codigo principal
2017-10-14 mais um pouco alto nivel no rasp e arrumar o codigo de andar, arquivo de comandos importantes SSH
2017-10-22 aumentando a certeza do giro e de andar reto, funfa tudo e danda limpada nos codigos
2017-10-24 Camera worked but vision algorithm is acting weird
2017-10-25 Baixo Nivel Garra
    Biblioteca de baixo nível para controle da garra.
    Necessário testar.
2017-10-25 Upgrade e correções
    Funções que faltavam adicionadas e correção nas existentes.
    Falta testar
2017-10-28 Termino das funções
    Todas as funções de baixo nível terminadas e código parcialmente testado.
2017-10-28 sensores testados e funfa, codigo locomocao arrumado, delicia
2017-10-30 Codigo Visao copo + arquivos testes
    Primeira tentativa de solução da identificação do copo. Imagens e videos usados para testes
2017-10-30 Estrutura finalizada
    Adicionada estrutura do código que faltava
2017-10-30 Código teste para a garra
2017-10-31 Tentando fazer o cow_pos voltar a funfar
2017-10-31 Removed low-pass filter from vision algorithm
2017-11-01 Teste da madrugada de terça
    Codigo testado e funcionando em boa parte dos casos
2017-11-01 testes da madruga
    eliminado copo esquerda, tentativa de encontrar como sem estar no template
2017-11-01 Codigo quase completo
    Copo mesmo fora do led é encontrado
2017-11-02 Corrigido erros com sensor de toque
    Esperado que todas as movimentações estão passiveis de serem interrompidas pelo toque.
    [GarraOpen.cpp]
2017-11-02 Video e codigo tanque
    Inicio da tentativa de encontrar o tanque
2017-11-02 Tentando selecionar maior contorno
    Apanhando mizeravelmente para o python
2017-11-03 codigo atrasado no commit
    Bugs de identação
    [copo.py]
2017-11-04 grafo do mapa com a funcao de buscar melhor caminho considerando os pesos
2017-11-04 arrumando os pesos e o algortimo para que ele considere distancias entre os nos
2017-11-05 reconhecer a arquitetura da cpu para poder abrir o arquivo do grafo e adicionando workspace do sublime com os atalhos
2017-11-05 ultima versao testada do codigo do arduino de locomocao
2017-11-05 integrando arduino com garra e testando sensores com novo numero de pinos
2017-11-08 planejador de rotas testado,andador entre nos, falta testar rotina da porta
2017-11-08 alteracoes no main paramelhorar os nomes e ultimos codigos do arduino
2017-11-08 Added camera.h file and prepared the code for the camera functions
2017-11-09 merjando os codigos dos arduinos
